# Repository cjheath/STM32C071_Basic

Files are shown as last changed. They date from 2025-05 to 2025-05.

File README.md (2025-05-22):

# STM32C071_Basic

A template project for STM32 projects using the STM32C071 32-pin QFP, with USB and SWD.
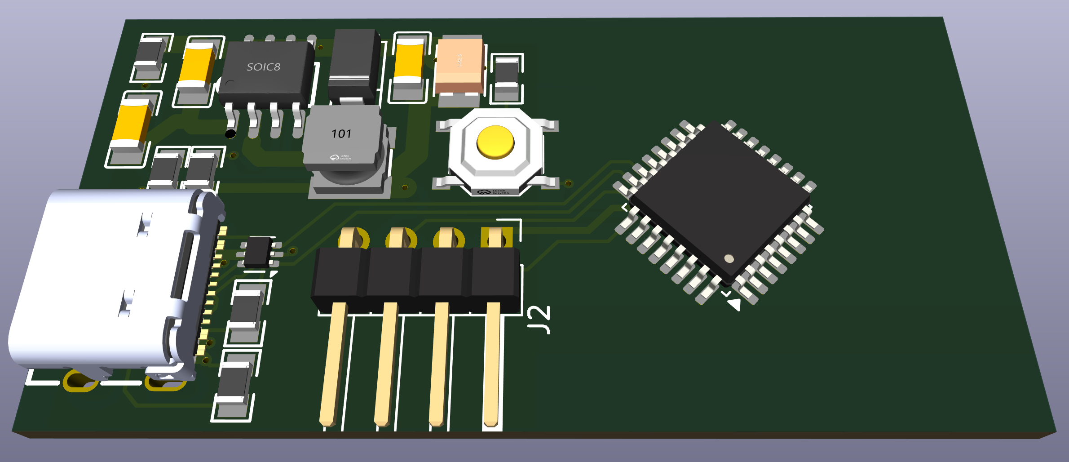
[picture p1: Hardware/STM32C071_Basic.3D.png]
3D view


## Goals and Status

This project provides a self-contained quick-start for projects
which require an easy-to-use USB-based micro-controller with Single-Wire-Debug (SWD),
such as for small test PCBs to evaluate new integrated circuit chips
that need configuration via SPI, I2C or UART
before integrating those chips into larger designs.

The following aspects are (to be) provided:

* Configuration
  - STM32CubeMX pin-configuration file you should edit for your required I/O configuration
* Hardware
  - KiCad schematic and 2-layer PCB containing the STM32, USB and SWD connectors
  - 3.3V Buck switcher from VBUS up to 20V (in case you use USB-PD)
  - KiCad project-local library of symbols, footprints and 3D models
  - LCSC ordering codes on all parts, to facilitate ordering on JLCPCB
* Firmware (incomplete)
  - Chip initialisation and peripheral setup firmware (NOT using the CubeMX-generated HAL code)
  - Basic USB device initialisation as a USB CDC-ish (USB serial) to support remote-control protocols
  - A Makefile for the firmware
* Host software (not started)
  - A simple command-line program for you to extend to add configuration commands

This template is still incomplete. Use at own risk

## How to use this template

View the README file in the Hardare directory. You may explore alternative MCU pin configurations
using either Kicad or by opening Configuration/STM32C071_Basic.ioc using STM32CubeMX.

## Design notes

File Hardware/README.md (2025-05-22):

# STM32C071_Basic Hardware

## Adapting the design to suit your project

Pin functions on the MCU are configured for minimum layout complexity
for UART, I2C and SPI, but KiCad knows what alternate functions are
possible. If you need different pin functions, you should reconfigure
them.

You may obviously change the size of the PCB by redrawing the Edge Cuts
rectangle.

## Libraries

This Kicad project has a local [project](project.kicad_sym) library and
uses [jlcbasic](https://github.com/cjheath/jlcbasic) and
[jlcpreferred](https://github.com/cjheath/jlcpreferred) libraries from
Github.  These libraries are expected to be checked-out somewhere
together, and this directory should contain a symbolic link to their
parent directory.  If you can't use a symbolic link, make the
(libraries)[libraries] directory and check out those projects inside
that.

## Hardware choices

So far as possible, parts are chosen to be easy for a relative novice to
hand-solder.  Accordingly, the smallest parts are 0805 packages, and the
MCU is a QFP, not a leadless version.  The cheapest possible parts have
been chosen throughout, with a preference for JLCPCB parts that have no
extra assembly changes.

# Power supply

The 3.2V power supply should be capable of more than 700mA, which is all
the power that 5V USB guarantees.  If you intend to use this much power,
you should increase the size of the tantalum capacitor on the output.

The power supply is designed to sink heat to the grond plane on the back
of the board. You might wish to remove the ground plane elsewhere, but
consider leaving it in this area if you need low noise or heatsinking.

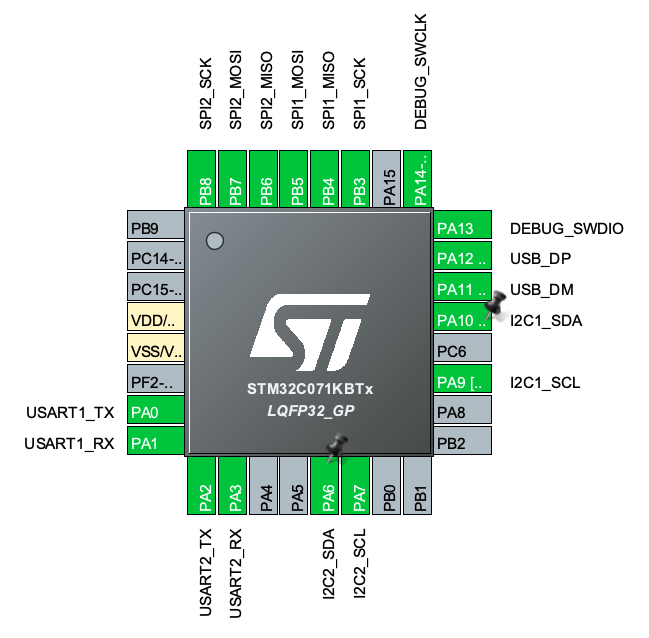
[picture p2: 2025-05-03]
Configuration/STM32C071_BasicPinout.png

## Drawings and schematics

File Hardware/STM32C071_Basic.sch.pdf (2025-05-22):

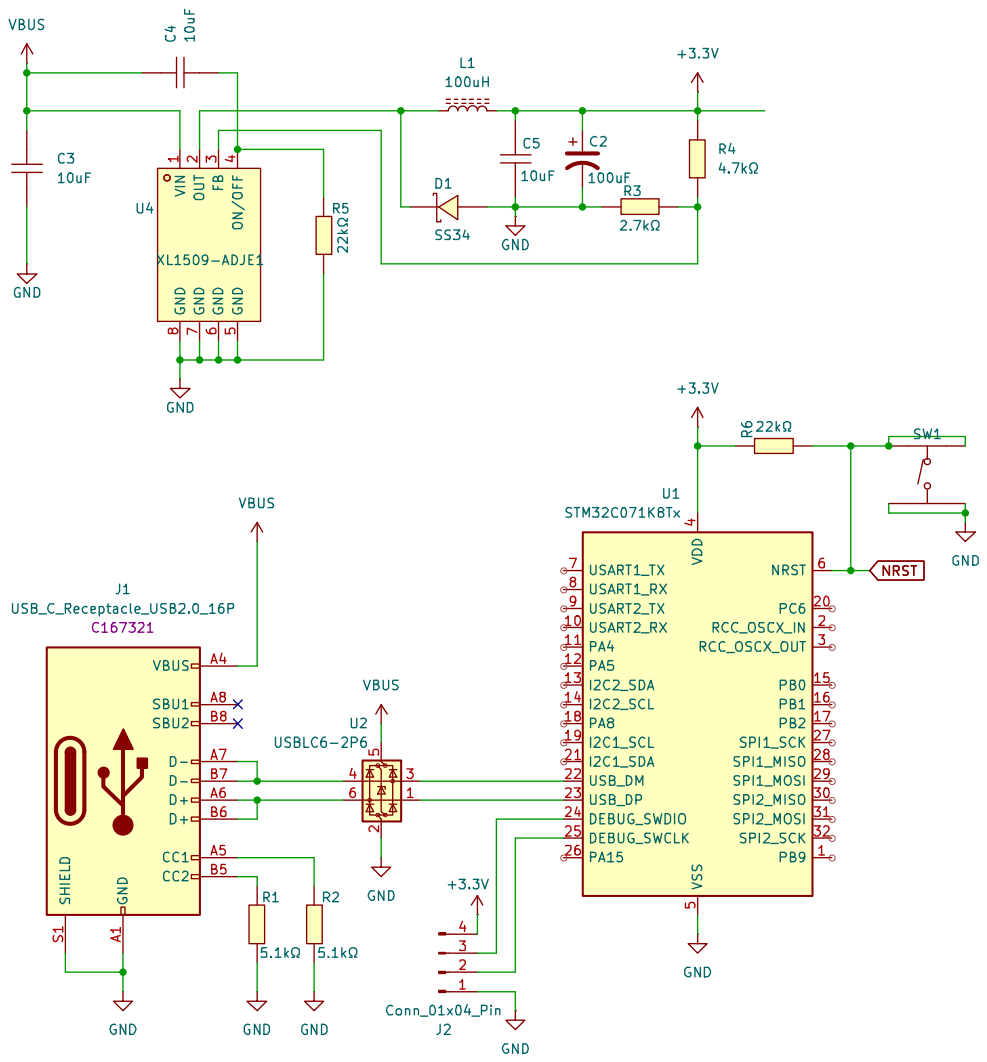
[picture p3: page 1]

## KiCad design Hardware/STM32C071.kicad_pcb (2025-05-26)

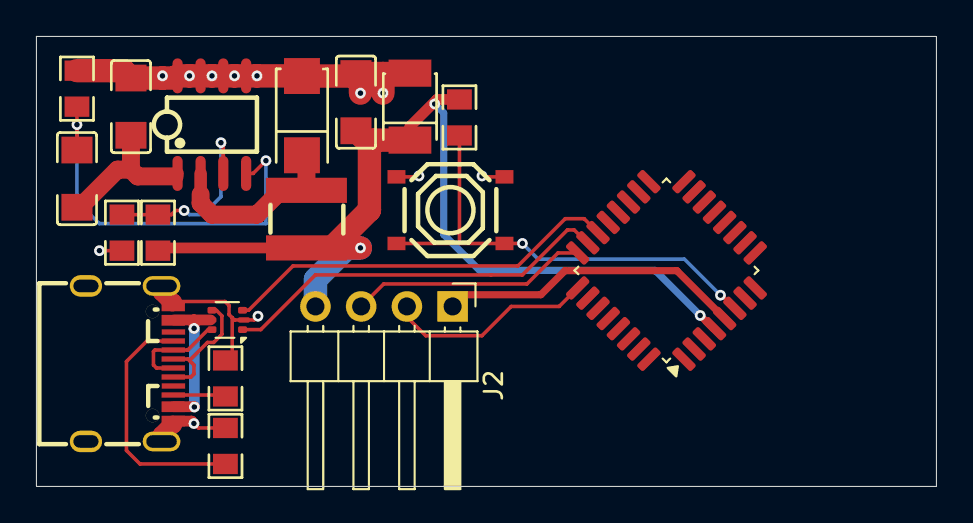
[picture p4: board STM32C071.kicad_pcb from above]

Board: 2 copper layers, 50.0 x 25.0 mm, 18 parts (0 on the bottom side), 15 nets.

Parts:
C2: 100uF; CASE-B_3528
C3, C4, C5: 10uF; C1206
D1: SS34; SMA_L4.3-W2.6-LS5.2-RD
J1: USB_C_Receptacle_USB2.0_16P; USB-C-SMD_TYPE-C-USB-17
J2: Conn_01x04_Pin; PinHeader_1x04_P2.54mm_Horizontal
L1: 100uH; IND-SMD_L4.0-W4.0_SMNR4030
R1, R2: 5.1kΩ; R0805
R3: 2.7kΩ; R0805
R4: 4.7kΩ; R0805
R5, R6: 22kΩ; R0805
SW1: TS-1187A-B-A-B; SW-SMD_4P-L5.1-W5.1-P3.70-LS6.5-TL_H1.5
U1: STM32C071K8Tx; LQFP-32_7x7mm_P0.8mm
U2: USBLC6-2P6; SOT-666
U4: XL1509-ADJE1; SOIC-8_L5.0-W4.0-P1.27-LS6.0-BL

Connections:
+3.3V: C2.1, C5.2, J2.4, L1.2, R4.2, R6.1, U1.4 (VDD)
GND: C2.2, C3.1, C5.1, D1.2 (A), J1.0, J1.A1 (GND), J1.A12 (GND), J2.1, R1.1, R2.2, R3.1, R5.2, SW1.3 (C), SW1.4 (D), U1.5 (VSS), U2.2 (GND), U4.5 (GND), U4.6 (GND), U4.7 (GND), U4.8 (GND)
NRST: R6.2, SW1.1 (A), SW1.2 (B), U1.6 (NRST)
unnamed: D1.1 (K), L1.1, U4.2 (OUT)
unnamed: J1.A5 (CC1), R2.1
unnamed: J1.B5 (CC2), R1.2
unnamed: J1.A6 (D+), J1.B6 (D+), U2.6 (I/O1)
unnamed: J1.A7 (D-), J1.B7 (D-), U2.4 (I/O2)
unnamed: J2.2, U1.25 (DEBUG_SWCLK)
unnamed: J2.3, U1.24 (DEBUG_SWDIO)
unnamed: U1.22 (USB_DM), U2.3 (I/O2)
unnamed: U1.23 (USB_DP), U2.1 (I/O1)
unnamed: R3.2, R4.1, U4.3 (FB)
unnamed: C4.1, R5.1, U4.4 (ON/OFF)
VBUS: C3.2, C4.2, J1.A4 (VBUS), J1.A9 (VBUS), U2.5 (VBUS), U4.1 (VIN)

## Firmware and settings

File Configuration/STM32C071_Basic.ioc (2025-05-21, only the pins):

Mcu.UserName=STM32C071KBTx
PA0.Signal=USART1_TX
PA1.Signal=USART1_RX
PA13.Signal=DEBUG_SWDIO
PA14-BOOT0.Signal=DEBUG_SWCLK
PA2.Signal=USART2_TX
PA3.Signal=USART2_RX
PA6.Signal=I2C2_SDA
PA7.Signal=I2C2_SCL
PB3.Signal=SPI1_SCK
PB4.Signal=SPI1_MISO
PB5.Signal=SPI1_MOSI
PB6.Signal=SPI2_MISO
PB7.Signal=SPI2_MOSI
PB8.Signal=SPI2_SCK

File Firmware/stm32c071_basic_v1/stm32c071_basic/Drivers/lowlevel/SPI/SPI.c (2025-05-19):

/*
 * SPI.c
 *
 *  Created on: May 6, 2025
 *      Author: IrBO25
 */

#include "SPI.h"

// simple access alias for SPI1
#define SPIx      SPI1
#define SPI_CLK() (RCC->APBENR2 |= RCC_APBENR2_SPI1EN)

// Pins PA4...PA7 on port A
#define GPIOA_CLK()  (RCC->IOPENR |= RCC_IOPENR_GPIOAEN)
#define PIN_SCK      5
#define PIN_MISO     6
#define PIN_MOSI     7
#define PIN_NSS      4

void SPI_LowLevel_Init(void) {

    GPIOA_CLK();
    SPI_CLK();


    // PA5, PA6, PA7 → AF mode
    GPIOA->MODER &= ~((3U<<(PIN_SCK*2)) | (3U<<(PIN_MISO*2)) | (3U<<(PIN_MOSI*2)));
    GPIOA->MODER |=  ((2U<<(PIN_SCK*2)) | (2U<<(PIN_MISO*2)) | (2U<<(PIN_MOSI*2)));
    // AFR0
    GPIOA->AFR[0] &= ~((0xFU<<(PIN_SCK*4)) | (0xFU<<(PIN_MISO*4)) | (0xFU<<(PIN_MOSI*4)));
    // AF0 = SPI1


    // 3) Configure PA4 as general-purpose output for software NSS

    GPIOA->MODER &= ~(3U<<(PIN_NSS*2));
    GPIOA->MODER |=  (1U<<(PIN_NSS*2));      // General purpose output
    GPIOA->OTYPER &= ~(1U<<PIN_NSS);         // Push-pull
    GPIOA->OSPEEDR |=  (3U<<(PIN_NSS*2));    // High speed
    GPIOA->PUPDR &= ~(3U<<(PIN_NSS*2));      // No pull
    GPIOA->ODR |=   (1U<<PIN_NSS);           // NSS = HIGH (inactive)

    // 4) Configure and enable SPI1 :
    // Master mode , Baudrate PCLK/8, CPOL=0, CPHA=0, 8-bit, SSI/SSM
    SPIx->CR1 = SPI_CR1_MSTR |
                SPI_CR1_SSI |
                SPI_CR1_SSM |
                (2U << SPI_CR1_BR_Pos);  // BR = 2 → fPCLK/8
    SPIx->CR1 |= SPI_CR1_SPE;              // Enable SPI
}
//Assert NSS (chip-select low)
void SPI_CS_Enable(void) {
    GPIOA->ODR &= ~(1U<<PIN_NSS);  // NSS = 0
}
// Deassert NSS (chip-select high)
void SPI_CS_Disable(void) {
    GPIOA->ODR |=  (1U<<PIN_NSS);  // NSS = 1
}
// Transmit one byte over SPI (blocking)
void SPI_TransmitByte(uint8_t data) {
    while (!(SPIx->SR & SPI_SR_TXE)); // wait until TX buffer is empty
    SPIx->DR = data;
    while (!(SPIx->SR & SPI_SR_RXNE)); // wait until RX buffer has data
    (void)SPIx->DR;  // Clear RX
}
// Receive one byte over SPI (blocking)
uint8_t SPI_ReceiveByte(void) {
    SPIx->DR = 0xFF;  //  send Dummy byte
    while (!(SPIx->SR & SPI_SR_RXNE)); // wait until data arrives
    return (uint8_t)SPIx->DR;
}
// Trnsmit 16 bits (MSB first)
void SPI_Transmit16(uint16_t data) {
    SPI_TransmitByte((uint8_t)(data >> 8));
    SPI_TransmitByte((uint8_t)(data & 0xFF));
}
//Receive 16 bits (MSB first)
uint16_t SPI_Receive16(void) {
    uint16_t hi = (uint16_t)SPI_ReceiveByte() << 8;
    uint16_t lo = (uint16_t)SPI_ReceiveByte();
    return (hi | lo);
}
// Trnsmit 24 bits (MSB first)
void SPI_Transmit24(uint32_t data) {
    SPI_TransmitByte((uint8_t)(data >> 16));
    SPI_TransmitByte((uint8_t)(data >>  8));
    SPI_TransmitByte((uint8_t)(data       ));
}
// Receive 24 bits (MSB first)
uint32_t SPI_Receive24(void) {
    uint32_t b1 = (uint32_t)SPI_ReceiveByte() << 16;
    uint32_t b2 = (uint32_t)SPI_ReceiveByte() << 8;
    uint32_t b3 = (uint32_t)SPI_ReceiveByte();
    return (b1 | b2 | b3);
}

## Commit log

2025-04-24 Initial Pin selection
2025-05-03 Added Kicad schematic with STM32C071 symbol adapted to the chosen pinout configuration
    [STM32F071.kicad_pcb, STM32F071.kicad_sch]
2025-05-03 Added libraries, CPU and USB hookup
    [STM32F071.kicad_sch]
2025-05-19 Added TPS5430 power supply. No decoupling or input caps yet
    [STM32F071.kicad_sch]
2025-05-19 More work on power supply
    [STM32F071.kicad_sch]
2025-05-19 Added 2n7002 to drive the power-on FET
    [STM32F071.kicad_sch]
2025-05-20 Changed power supply to XL1509. Started PCB. No inductor yet
    [STM32F071.kicad_pcb, STM32F071.kicad_sch]
2025-05-21 New Power supply and USB connector laid out
    [STM32F071.kicad_pcb, STM32F071.kicad_sch]
2025-05-21 Corrected STM32 file names
    [STM32C071.kicad_pcb, STM32C071.kicad_sch]
2025-05-21 Added SWD connector and 3D view
    [STM32C071.kicad_pcb, STM32C071.kicad_sch]
2025-05-21 Fixed project library paths
    [STM32C071.kicad_pcb]
2025-05-22 Added Reset and power connections, 45 rotation
    [STM32C071.kicad_pcb, STM32C071.kicad_sch]
2025-05-26 Grounded USB-C mounting pins
    [STM32C071.kicad_pcb]
